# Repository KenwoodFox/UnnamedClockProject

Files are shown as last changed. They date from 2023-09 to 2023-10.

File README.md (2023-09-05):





# UnnamedClockProject

Banner

This repo contains all the firmware and hardware for the UnnamedClockProject.

If you're looking for the latest docs/builds, see our [Releases Page](https://github.com/KenwoodFox/UnnamedClockProject/releases).

# Getting Started

First, clone this repo (and optionally checkout a branch)

```shell
git clone https://github.com/KenwoodFox/UnnamedClockProject.git
cd UnnamedClockProject
git checkout new_board
```

# Init Submodules

Some libraries and resources are included as submodules, run the following
command to initialize them before opening the main sch

(If you get a missing library error, make sure to do this)

```shell
git submodule update --init --recursive
```

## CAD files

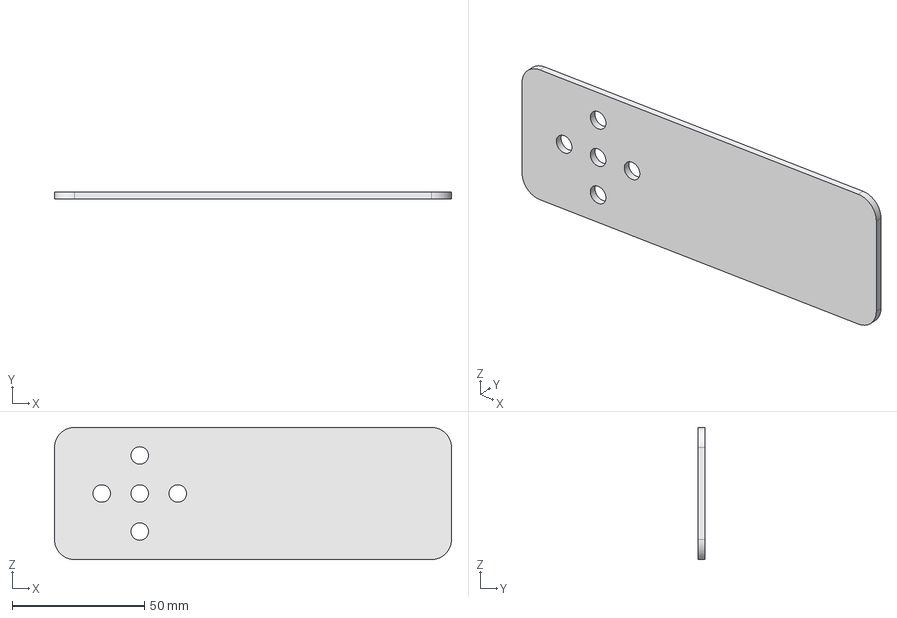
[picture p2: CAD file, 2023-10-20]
CAD/Bezel.FCStd
150.0 x 2.54 x 50.0 mm

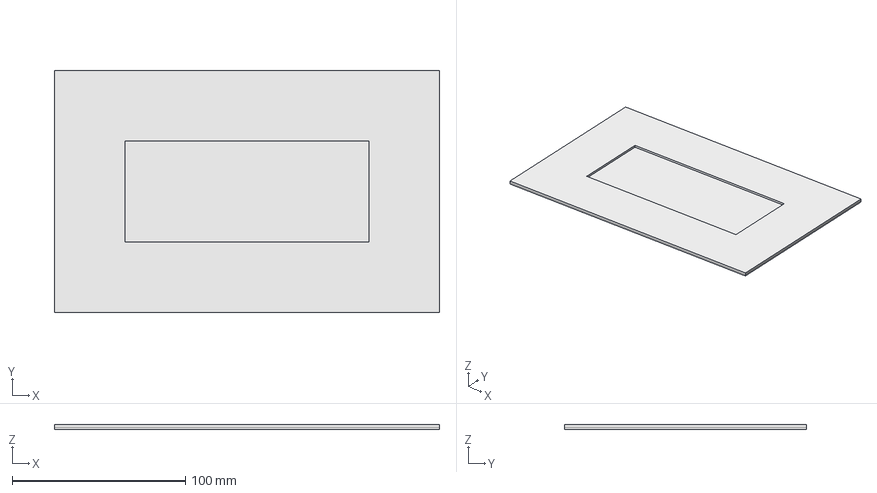
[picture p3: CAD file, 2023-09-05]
Hardware/UnnamedClockProject/Stencils/SolderMaskStencil.FCStd
222.2 x 139.7 x 2.60 mm

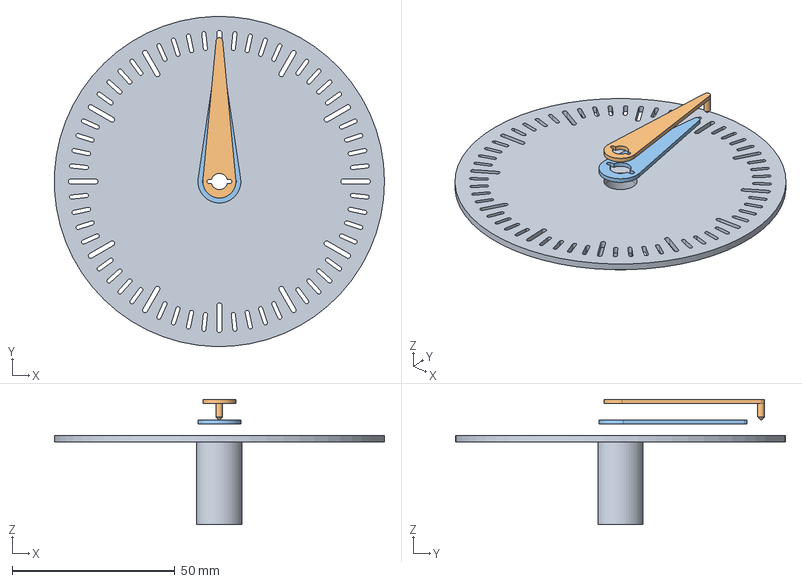
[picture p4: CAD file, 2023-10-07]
CAD/JigsAndFixtures.FCStd
101.5 x 101.6 x 38.5 mm
Clock Face
NewMinuteHand
NewHourHand

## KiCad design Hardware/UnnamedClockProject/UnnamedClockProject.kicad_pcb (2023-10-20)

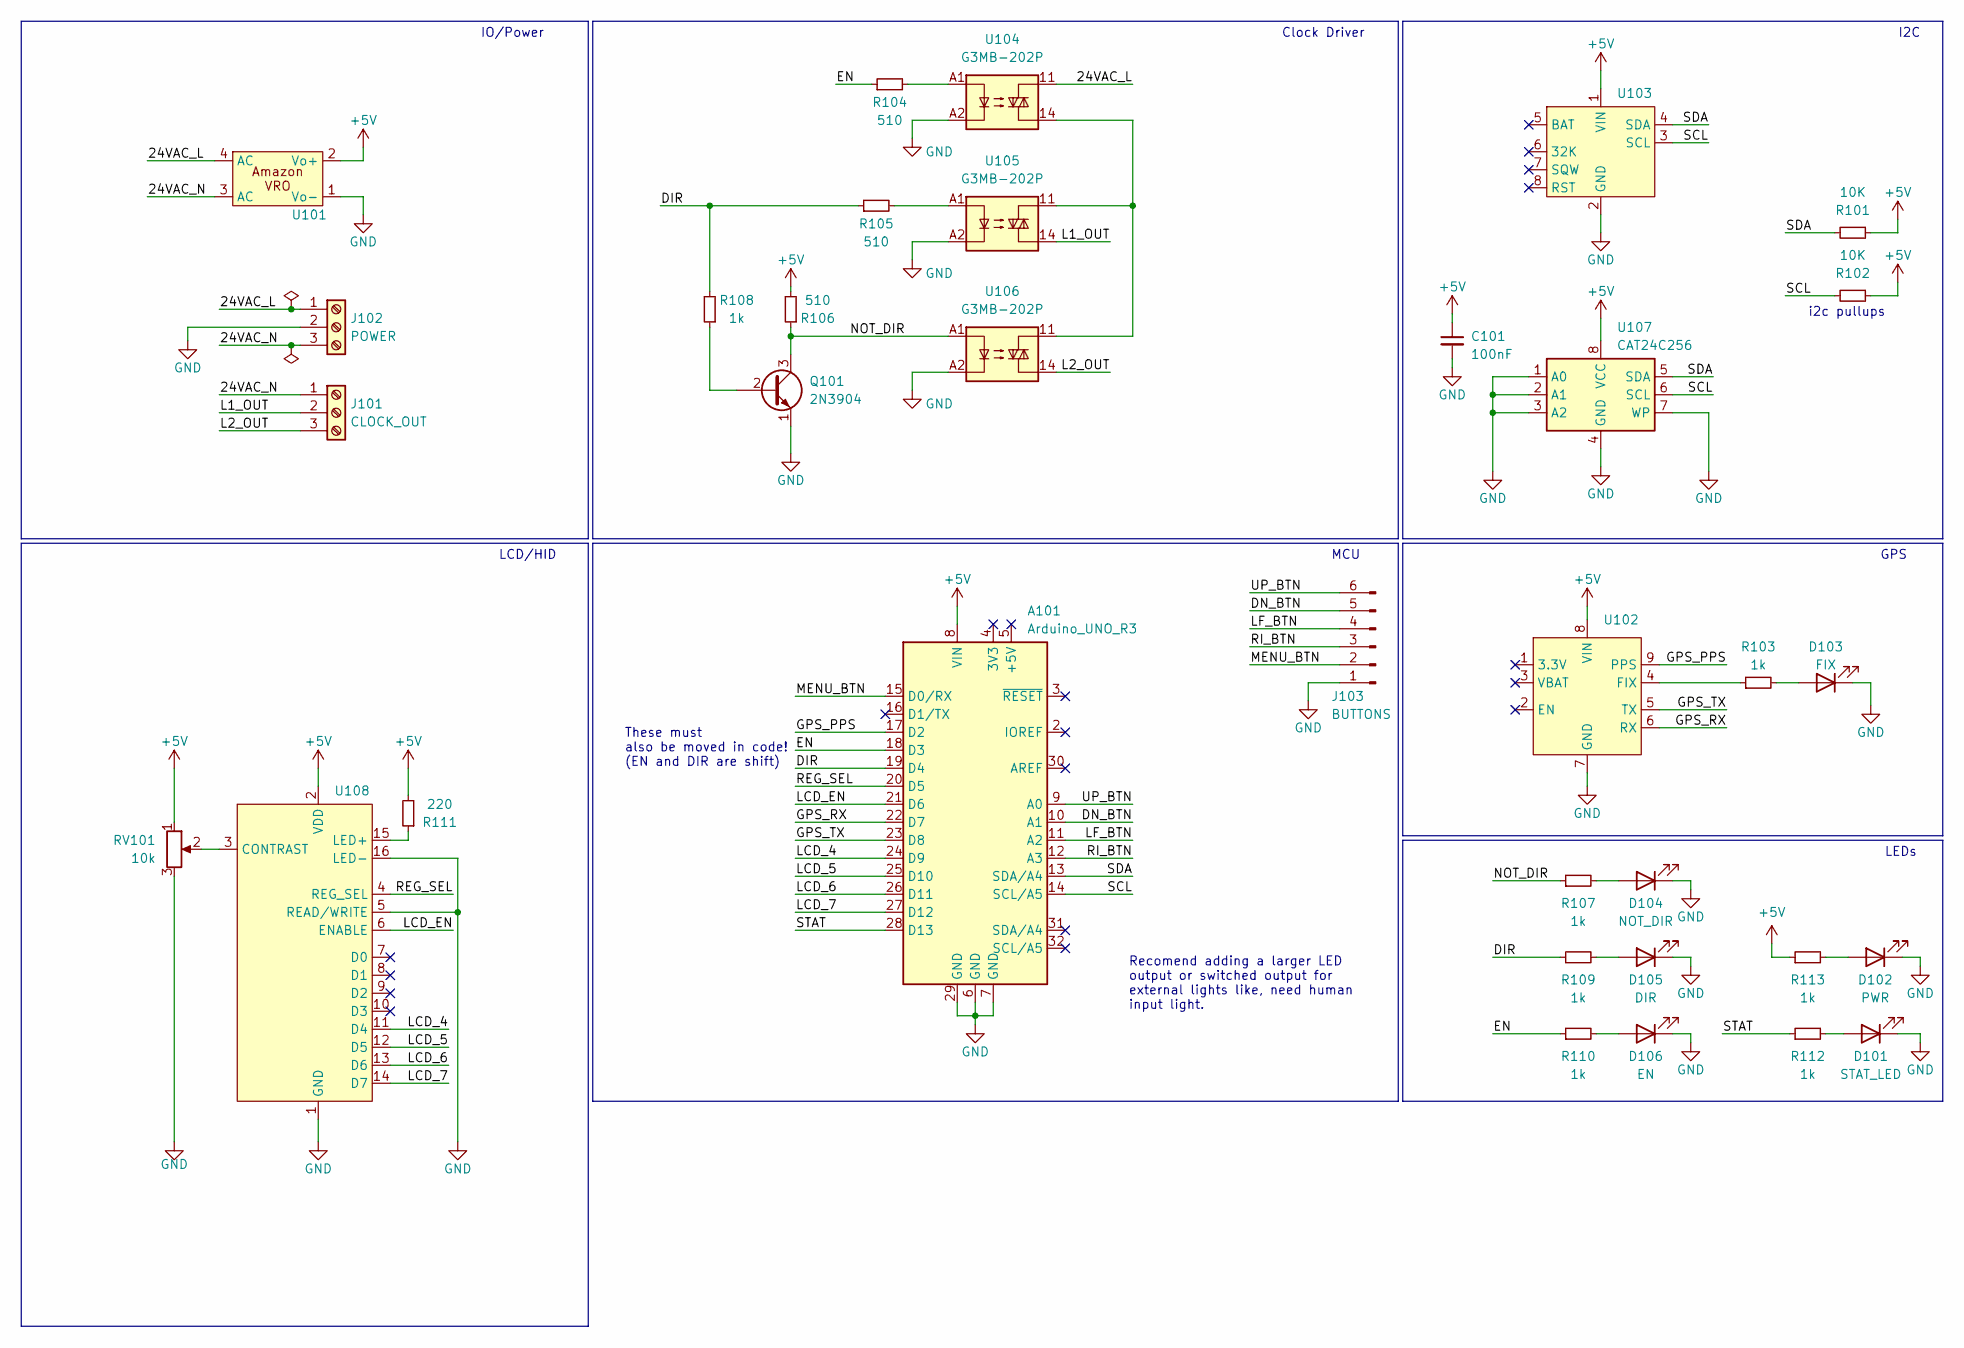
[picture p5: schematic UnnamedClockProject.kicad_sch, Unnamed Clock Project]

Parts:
A101: Arduino_UNO_R3; Arduino_Uno_Nano_Combo
C101: 100nF; C_Disc_D5.0mm_W2.5mm_P5.00mm
D101: STAT_LED; LED_D5.0mm
D102: PWR; LED_D5.0mm
D103: FIX; LED_D5.0mm
D104: NOT_DIR; LED_D5.0mm
D105: DIR; LED_D5.0mm
D106: EN; LED_D5.0mm
J101: CLOCK_OUT; TerminalBlock_Phoenix_MKDS-1,5-3_1x03_P5.00mm_Horizontal
J102: POWER; TerminalBlock_Phoenix_MKDS-1,5-3_1x03_P5.00mm_Horizontal
J103: BUTTONS; JST_EH_B6B-EH-A_1x06_P2.50mm_Vertical
Q101: 2N3904; TO-92_Inline
R101, R102: 10K; R_Axial_DIN0207_L6.3mm_D2.5mm_P10.16mm_Horizontal
R103, R107, R108, R109, R110, R112, R113: 1k; R_Axial_DIN0207_L6.3mm_D2.5mm_P10.16mm_Horizontal
R104, R105, R106: 510; R_Axial_DIN0207_L6.3mm_D2.5mm_P10.16mm_Horizontal
R111: 220; R_Axial_DIN0207_L6.3mm_D2.5mm_P10.16mm_Horizontal
RV101: 10k; Potentiometer_Runtron_RM-065_Vertical
U101: Amazon_DRO
U102: Ultimate GPS Breakout V3 Module
U103: DS3231
U104, U105, U106: G3MB-202P; OptoRelay
U107: CAT24C256; DIP-8_W7.62mm
U108: 2x16_LCD

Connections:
+5V: A101.8 (VIN), C101.1, R101.1, R102.1, R106.2, R111.2, R113.1, RV101.1, U101.2 (Vo+), U102.8 (VIN), U103.1 (VIN), U107.8 (VCC), U108.2 (VDD)
/24VAC_L: J102.1, U101.4 (AC), U104.11
/24VAC_N: J101.1, J102.3, U101.3 (AC)
/DIR: A101.19 (D4), R105.1, R108.2, R109.1
/DN_BTN: A101.10 (A1), J103.5
/EN: A101.18 (D3), R104.1, R110.1
/GPS_PPS: A101.17 (D2), U102.9 (PPS)
/GPS_RX: A101.22 (D7), U102.6 (RX)
/GPS_TX: A101.23 (D8), U102.5 (TX)
/L1_OUT: J101.2, U105.14
/L2_OUT: J101.3, U106.14
/LCD_4: A101.24 (D9), U108.11 (D4)
/LCD_5: A101.25 (D10), U108.12 (D5)
/LCD_6: A101.26 (D11), U108.13 (D6)
/LCD_7: A101.27 (D12), U108.14 (D7)
/LCD_EN: A101.21 (D6), U108.6 (ENABLE)
/LF_BTN: A101.11 (A2), J103.4
/MENU_BTN: A101.15 (D0/RX), J103.2
/NOT_DIR: Q101.3 (C), R106.1, R107.1, U106.A1
/REG_SEL: A101.20 (D5), U108.4 (REG_SEL)
/RI_BTN: A101.12 (A3), J103.3
/SCL: A101.14 (SCL/A5), R102.2, U103.3 (SCL), U107.6 (SCL)
/SDA: A101.13 (SDA/A4), R101.2, U103.4 (SDA), U107.5 (SDA)
/STAT: A101.28 (D13), R112.1
/UP_BTN: A101.9 (A0), J103.6
GND: A101.6 (GND), A101.7 (GND), A101.29 (GND), C101.2, D101.1 (K), D102.1 (K), D103.1 (K), D104.1 (K), D105.1 (K), D106.1 (K), J102.2, J103.1, Q101.1 (E), RV101.3, U101.1 (Vo-), U102.7 (GND), U103.2 (GND), U104.A2, U105.A2, U106.A2, U107.1 (A0), U107.2 (A1), U107.3 (A2), U107.4 (GND), U107.7 (WP), U108.1 (GND), U108.5 (READ/WRITE), U108.16 (LED-)
unnamed: D101.2 (A), R112.2
unnamed: D102.2 (A), R113.2
unnamed: D103.2 (A), R103.2
unnamed: D104.2 (A), R107.2
unnamed: D105.2 (A), R109.2
unnamed: D106.2 (A), R110.2
unnamed: Q101.2 (B), R108.1
unnamed: R104.2, U104.A1
unnamed: R105.2, U105.A1
unnamed: R103.1, U102.4 (FIX)
unnamed: U104.14, U105.11, U106.11
unnamed: RV101.2, U108.3 (CONTRAST)
unnamed: R111.1, U108.15 (LED+)

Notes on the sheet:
GPS
These must also be moved in code! (EN and DIR are shift)
Clock Driver
LCD/HID
IO/Power
MCU
Recomend adding a larger LED output or switched output for external lights like, need human input light.
LEDs
i2c pullups
I2C

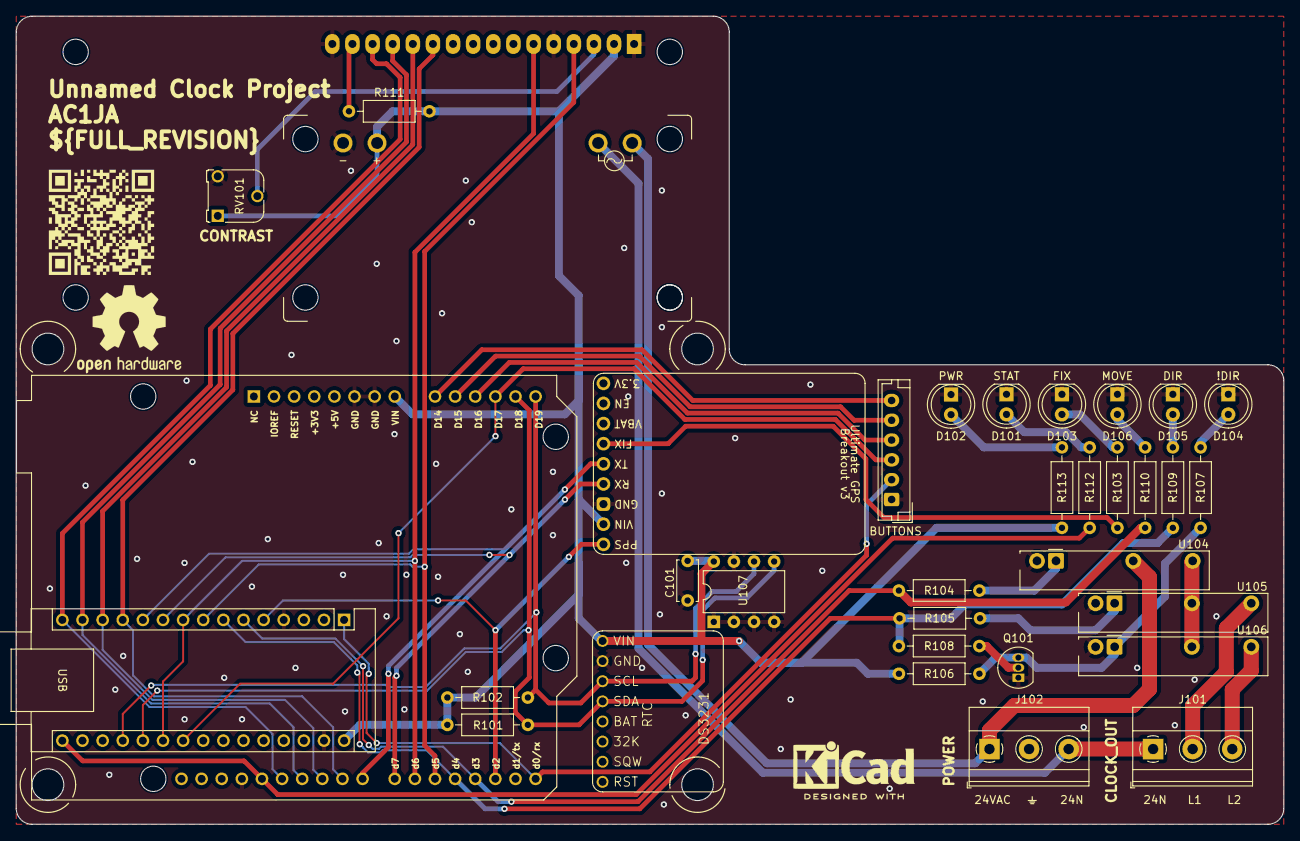
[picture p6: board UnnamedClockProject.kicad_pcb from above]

Board: 2 copper layers, 160.0 x 102.0 mm, 34 parts (1 on the bottom side), 39 nets.

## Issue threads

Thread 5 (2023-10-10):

Solid State Relay footprint wrong size!

KenwoodFox, 2023-10-10:
Footprint is the wrong size.

Closed 2023-10-20.

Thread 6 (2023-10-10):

Mounting Holes in #v0.1 board

KenwoodFox, 2023-10-10:
Some holes are the wrong size.

Closed 2023-10-15.

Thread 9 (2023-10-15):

Timezone (static/simple)

KenwoodFox, 2023-10-15:
Implement simple ETC timezone (with integration into clock advance system)

KenwoodFox, 2023-10-16:
This will get fixed in #10

KenwoodFox, 2023-10-20:
This only partially got fixed in #10 see specifically https://github.com/KenwoodFox/UnnamedClockProject/blob/5-solid-state-relay-footprint-wrong-size/Firmware/include/timeTools.h

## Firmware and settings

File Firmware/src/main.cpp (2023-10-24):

/**
 * @brief Todo!
 */

#include "Arduino.h"
#include <Arduino_FreeRTOS.h>
#include <TinyGPSPlus.h>
#include <SoftwareSerial.h>
#include <ArduinoLog.h>
#include <Bounce2.h>
#include <LiquidCrystal.h>
// #include <Timezone.h>
// #include <RTClib.h>

#include "Clock.h"
#include "boardPins.h"
#include "menuEnum.h"
#include "customChars.h"
#include "timeTools.h"

// Config
static const uint32_t GPSBaud = 9600;
static const int mvmtTime = 10 * 1000; // Movement time in ms
static const int pauseTime = 2 * 1000; // Time between moves

// Objects
SoftwareSerial ss(RX_PIN, TX_PIN);
TinyGPSPlus gps;
LiquidCrystal lcd(LCD_RS, LCD_EN, LCD_D4, LCD_D5, LCD_D6, LCD_D7);
Clock clock(EN_PIN, DIR_PIN);
// RTC_DS3231 rtc;

// Buttons
Bounce2::Button upBtn = Bounce2::Button();
Bounce2::Button downBtn = Bounce2::Button();
Bounce2::Button leftBtn = Bounce2::Button();
Bounce2::Button righBtn = Bounce2::Button();
Bounce2::Button menuBtn = Bounce2::Button();

// Task Handlers
TaskHandle_t TaskDriver_Handler;
TaskHandle_t TaskInterface_Handler;

// Special modes
bool manualOverride = false; // Used when manually overriding

// // Timezone
// TimeChangeRule myDST = {"EDT", Second, Sun, Mar, 2, -240}; // Daylight time = UTC - 4 hours
// TimeChangeRule mySTD = {"EST", First, Sun, Nov, 2, -300};  // Standard time = UTC - 5 hours
// Timezone myTZ(myDST, mySTD);

// Defs
void displayInfo();
void TaskDriver(void *pvParameters);
void TaskInterface(void *pvParameters);

void setup()
{
  // Begin
  Serial.begin(115200);
  ss.begin(GPSBaud);
  Log.begin(LOG_LEVEL_VERBOSE, &Serial);

  Log.infoln(F("Starting version %s"), REVISION);

  /**
   * Because memory is limited, lets try and have
   * as few tasks as possible running.
   */

  // Setup tasks
  Log.infoln(F("Starting Task Driver"));
  xTaskCreate(
      TaskDriver,           // A pointer to this task in memory
      "Driver",             // A name just for humans
      160,                  // This stack size can be checked & adjusted by reading the Stack Highwater
      NULL,                 // Parameters passed to the task function
      2,                    // Priority, with 2 (configMAX_PRIORITIES - 1) being the highest, and 0 being the lowest.
      &TaskDriver_Handler); // Task handle

  Log.infoln(F("Starting Task Interface"));
  xTaskCreate(
      TaskInterface, // Handles human interface and serial interface
      "Interface",
      200,
      NULL,
      2,
      &TaskInterface_Handler);
}

void loop()
{
  // Empty. Things are done in Tasks.
  // vTaskDelete(NULL); // Exit task
}

void TaskDriver(void *pvParameters)
{
  (void)pvParameters;

  // Begin
  Log.infoln(F("Created %s Task, heap size is %d"), pcTaskGetName(NULL), uxTaskGetStackHighWaterMark(NULL));

  // Setup for this task
  pinMode(LED_BUILTIN, OUTPUT);
  clock.begin();
  // rtc.begin();

  // Prev time
  TickType_t prevTime;

  // Local
  int watermark = 99999;

  // "Loop"
  for (;;)
  {
    // Move clock
    if (gps.time.isValid())
    { // Ready condition here
      if (clock.needAdvance() || manualOverride)
      {
        Log.verboseln(F("Moving clock, %d to %d."), clock.getMinute(), gps.time.minute()); // The minute will never change
        clock.autoMove(true);                                                              // Begin move
        xTaskDelayUntil(&prevTime, mvmtTime / portTICK_PERIOD_MS);                         // Time spent moving
        clock.next();                                                                      // Auto advance to the next
        xTaskDelayUntil(&prevTime, pauseTime / portTICK_PERIOD_MS);                        // Time between moves
      }
      else
      {
        clock.move(false, false); // Stop moving
      }
    }

    clock.setTarget(gps.time.minute(), getLocalHour(gps.time.hour())); // Set the target

    // Blinky
    digitalWrite(LED_BUILTIN, gps.time.second() % 2 == 0); // TODO: Move me, misc function

    // Waterline
    if (uxTaskGetStackHighWaterMark(NULL) < watermark) // TODO: Move me, misc function
    {
      watermark = uxTaskGetStackHighWaterMark(NULL);
      Log.warningln(F("%s: Watermark dropped to %d bytes."), pcTaskGetName(NULL), watermark);
    }

    xTaskDelayUntil(&prevTime, 100 / portTICK_PERIOD_MS); // Wait to resume
  }
}

// Daylight savings code automatic
// christinsen timezone code <- have to get this working right eventually
// Do the catchup/set code!
// Hardcode the timeozne library! <- Christen
// Wire in the RTC today <-

// Move me somewhere else!
void TaskInterface(void *pvParameters)
{
  (void)pvParameters;

  // Begin
  Log.infoln(F("Created %s Task, heap size is %d"), pcTaskGetName(NULL), uxTaskGetStackHighWaterMark(NULL));

  // Setup (lcd)
  lcd.begin(16, 2);
  lcd.print(F("UCC Version"));
  lcd.setCursor(0, 1);
  lcd.print(REVISION);

  // Prev time
  TickType_t prevTime;

  // Local
  int watermark = 99999;

  // Setup (custom chars)
  lcd.createChar(0, upChar);
  lcd.createChar(1, downChar);
  lcd.createChar(2, clockAChar);
  lcd.createChar(3, clockBChar);
  lcd.createChar(4, clockCChar);
  lcd.createChar(5, clockDChar);

  // Setup (Buttons)
  upBtn.attach(UP_PIN, INPUT_PULLUP);
  downBtn.attach(DOWN_PIN, INPUT_PULLUP);
  leftBtn.attach(LEFT_PIN, INPUT_PULLUP);
  righBtn.attach(RIGH_PIN, INPUT_PULLUP);
  menuBtn.attach(MENU_PIN, INPUT_PULLUP);

  // Menu index/temp values
  Menu menuIdx = ClockSet;
  char _lineBuf[17]; // Screen is 16 long but null term is extra undrawn byte
  SetPos pos = None;
  int _HrToSet = 0;   // The hour we will set
  int _MinToSet = 0;  // The minute we will set
  uint8_t _hrpos = 0; // The x location of the hour number (always 6 when we start running this menu)

  for (uint8_t i = 0; i < 5; i++)
  {
    vTaskDelay(1000 / portTICK_PERIOD_MS);
  }

  // "Loop"
  for (;;)
  {
    // Update buttons
    upBtn.update();
    downBtn.update();
    leftBtn.update();
    righBtn.update();
    menuBtn.update();

    switch (menuIdx)
    {
    case Status:;
      lcd.setCursor(0, 0);
      if (gps.date.isValid() && gps.satellites.value() >= 4)
      {
        lcd.print(F("GPS Ready."));
      }
      else
      {
        lcd.print(F("Wait for GPS..."));
        lcd.setCursor(0, 1);
        lcd.print(gps.satellites.value());
        lcd.print(F("/4 Satellites."));
      }
      break;

    case ClockSet:;
      // Check if we're setting something

      _hrpos = 6;

      switch (pos)
      {
      case Minute:;
        _hrpos += 3; // Scoot to the right to cover the minute

        if (upBtn.pressed())
        {
          _MinToSet++;
          _MinToSet = _MinToSet % 60;
        }

        if (downBtn.pressed())
        {
          _MinToSet--;
          _MinToSet < 0 ? _MinToSet = 59 : _MinToSet = _MinToSet;
        }

      case Hour:;
        // Dont move if we're setting time!
        clock.setMovementEnabled(false);

        // One last check to make sure this loop is simple (dont overrun this segment)
        if (pos != Minute)
        {
          if (upBtn.pressed())
          {
            _HrToSet++;
            _HrToSet = _HrToSet % 12;
          }

          if (downBtn.pressed())
          {
            _HrToSet--;
            _HrToSet < 0 ? _HrToSet = 12 : _HrToSet = _HrToSet;
          }
        }

        lcd.setCursor(_hrpos, 1);
        if (millis() % 1000 < 500)
        {
          // Blank over
          lcd.print("  ");
        }
        else
        {
          // Print the blinking 2 digit number
          sprintf(_lineBuf, "%02d", pos == Minute ? _MinToSet : _HrToSet);
          lcd.print(_lineBuf);
        }
        break;

      case None:;
        // Check if inputs were set
        if (_HrToSet + _MinToSet > 0)
        {
          // Push them to the clock
          clock.setTime(_MinToSet, _HrToSet);
          _MinToSet = 0;
          _HrToSet = 0;
          clock.setMovementEnabled(true);
        }

      default:
        lcd.setCursor(0, 0);
        lcd.print(F("Set Time    "));
        lcd.setCursor(0, 1);
        sprintf(_lineBuf, "%02d:%02d %02d:%02d (%02d)", getLocalHour(gps.time.hour()), gps.time.minute(), clock.getHour(), clock.getMinute(), gps.time.second());
        lcd.print(_lineBuf);
        break;
      }

      // Accept button inputs
      if (menuBtn.pressed())
      {
        pos++;
        Log.infoln(F("Pos is now %d"), pos);
      }
      break;

    case ManualMode:;
      lcd.setCursor(0, 0);
      lcd.print(F("Manual Mode"));

      // Update manual override
      manualOverride = !upBtn.isPressed();
      clock.setMovementEnabled(true);

      break;

    case LeftHandedNess:;
      lcd.setCursor(0, 0);
      lcd.print(F("Left hand L1L2?"));
      lcd.setCursor(0, 1);
      sprintf(_lineBuf, "isLeftHanded %d", clock.setLeftHanded());
      lcd.print(_lineBuf);

      if (upBtn.pressed() || downBtn.pressed())
      {
        clock.setLeftHanded(true);
      }

      break;

    default:
      /* Not to be confused with Status (the enum) this is the fallthrough, we should never get here! */
      lcd.setCursor(0, 0);
      lcd.print(F("Error: No Menu!"));
      break;
    }

    if (righBtn.pressed())
    {
      menuIdx++;
      lcd.clear();
    }

    if (leftBtn.pressed())
    {
      menuIdx--;
      lcd.clear();
    }

    // Overlays!
    lcd.setCursor(15, 0);
    if (clock.needAdvance() || manualOverride)
    {
      lcd.write((byte)((gps.time.second() % 4) + 2));
    }
    else
    {
      lcd.write((byte)3);
    }

    // Process GPS
    while (ss.available() > 0)
    {
      if (gps.encode(ss.read()))
        ;
      // displayInfo();
    }

    // Other stuff
    // Waterline
    if (uxTaskGetStackHighWaterMark(NULL) < watermark)
    {
      watermark = uxTaskGetStackHighWaterMark(NULL);
      Log.warningln(F("%s: Watermark dropped to %d bytes."), pcTaskGetName(NULL), watermark);
    }

    xTaskDelayUntil(&prevTime, 40 / portTICK_PERIOD_MS);
  }
}

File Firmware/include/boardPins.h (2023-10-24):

#ifndef _BOARD_PINS_H
#define _BOARD_PINS_H

// LEDs
#define DIR_PIN 4
#define EN_PIN 3

// GPS
// #define PPS 9 // Change me!
#define RX_PIN 8
#define TX_PIN 7

// LCD
#define LCD_EN 6
#define LCD_RS 5
#define LCD_D4 9
#define LCD_D5 10
#define LCD_D6 11
#define LCD_D7 12

// Buttons
#define UP_PIN A0
#define DOWN_PIN A1
#define LEFT_PIN A2
#define RIGH_PIN A3
#define MENU_PIN 0

#endif

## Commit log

2023-09-05 Import from cookiecutter https://github.com/KenwoodFox/Project-Template
    [Cube.FCStd, SolderMaskStencil.FCStd, UnnamedClockProject.kicad_pcb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]
2023-09-05 Add basics
    [UnnamedClockProject.kicad_pcb, UnnamedClockProject.kicad_sch]
2023-09-07 Bump upstream libs
    [UnnamedClockProject.kicad_sch]
2023-09-08 Add new design with solid state relays
    [UnnamedClockProject.kicad_pcb, UnnamedClockProject.kicad_sch]
2023-09-08 Add footprints
    [UnnamedClockProject.kicad_sch]
2023-09-08 Add plugs
    [UnnamedClockProject.kicad_sch]
2023-09-08 Tie into mcu
    [UnnamedClockProject.kicad_sch]
2023-10-07 RTOS layout and first tasks (#2)
    Code here is stable, and testable. But features are still missing.
    We've submitted the v0.1 board design, so its time to refine the code.
    [Cube.FCStd, JigsAndFixtures.FCStd, UnnamedClockProject.kicad_pcb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]
2023-10-07 Stable Firmware (#4)
    [UnnamedClockProject.kicad_pcb]
2023-10-10 Add 3d models
    [UnnamedClockProject.kicad_pcb, UnnamedClockProject.kicad_sch]
2023-10-15 Fix mounting holes (#7)
    [UnnamedClockProject.kicad_pcb]
2023-10-20 Fix optorelays not fitting (#8)
    This is fine for now, merging mostly because so many code improvements now depend on this branch!
    [Bezel.FCStd, UnnamedClockProject.kicad_pcb, UnnamedClockProject.kicad_sch]
